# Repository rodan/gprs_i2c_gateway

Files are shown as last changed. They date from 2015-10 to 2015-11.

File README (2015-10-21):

  this is a re-run of a previous project [1], 
  but instead of the Atmel AVR 328p a Texas Instruments MSP430F5510 is used

  it is still under development, but the firmware will be able to

   - talk to a number of i2c sensors
   - buffer data into a fram memory chip
   - send data via gprs to an online server
   - use a minimal amount of energy

  there are 3 components in this repository:
  firmware  - contains the C code for the microcontroller
  hardware  - open source hardware for the main board
  server    - server-side implementation of the comm protocol

  * library dependencies for the included avr software:
  none - all is included in the repo

  * compiler toolchain used (gentoo):
        msp430-gcc-4.6.3_p20120406
        msp430mcu-20120716
        msp430-binutils-2.22_p20120911
        msp430-libc-20120716
        mspdebug-0.21

  * development is done using
        MSP430-5510STK [2]

  * dependencies for the server-side software:

  sqlite      http://www.sqlite.org/
  gnuplot     http://www.gnuplot.info/

  * sensors used:

  SHT15 Humidity and Temperature Sensor
  Honeywell HSCMRNN030PA2A3 pressure sensor - mouser part: 785-HSCMRNN030PA2A3

  Author:          Petre Rodan <petre.rodan@simplex.ro>
  Available from:  https://github.com/rodan/gprs_i2c_gateway
  License:         GNU GPLv3

[1]  https://github.com/rodan/solar-sensor
[2]  https://www.olimex.com/Products/MSP430/Starter/MSP430-5510STK/

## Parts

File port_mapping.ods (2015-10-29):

Project: | gprs i2c gateway
port | designation | use | PxDIR - in=0, out=1 | PxSEL - special fct disabled=0 enabled=1 | PxOUT - low=0, high=1 | PxREN - pullup(down)disabled=0 enabled=1
P1.0 | TA0CLK/ACLK |  | 0 | 0 | 0 | 0
P1.1 | TA0.0 | CE | 1 | 0 | 0 | 0
P1.2 | TA0.1 | CHG | 0 | 0 | 0 | 0
P1.3 | TA0.2 | RTS _O | 1 | 0 | 0 | 0
P1.4 | TA0.3 | CTS _I | 0 | 0 | 0 | 1
P1.5 | TA0.4 | RI _I | 0 | 0 | 0 | 0
P1.6 | TA1CLK | DTR _O | 1 | 0 | 0 | 0
P1.7 | TA1.0 |  | 0 | 0 | 0 | 0
 |  |  | 4A | 00 | 00 | 10
P2.0 | TD0 |  | 0 | 0 | 0 | 0
 |  |  | 00 | 00 | 00 | 00
P4.0 | PM_UCB1STE/PM_UCA1CLK | GPRS_PWRKEY _O | 1 | 0 | 0 | 0
P4.1 | PM_UCB1SIMO/PM_UCB1SDA | GPRS_VBAT _O | 1 | 0 | 0 | 0
P4.2 | PM_UCB1SOMI/PM_UCB1SCL | uart rx | 0 | 0 | 0 | 0
P4.3 | PM_UCB1CLK/PM_UCA1STE | uart tx | 0 | 0 | 0 | 0
P4.4 | PM_UCA1TXD/PM_UCA1SIMO | gprs rx | 0 | 0 | 0 | 0
P4.5 | PM_UCA1RXD/PM_UCA1SOMI | gprs tx | 0 | 0 | 0 | 0
P4.6 | PM_NONE | SCL | 1 | 0 | 0 | 0
P4.7 | PM_NONE | SDA | 1 | 0 | 0 | 0
 |  |  | C3 | 00 | 00 | 00
P5.0 | A8/VeREF+ |  | 0 | 0 | 0 | 0
P5.1 | A9/VeREF- |  | 0 | 0 | 0 | 0
P5.2 | XT2IN |  | 0 | 0 | 0 | 0
P5.3 | XT2OUT |  | 0 | 0 | 0 | 0
P5.4 | XIN | LF crystal | 0 | 1 | 0 | 0
P5.5 | XOUT | LF crystal | 0 | 1 | 0 | 0
 |  |  | 00 | 30 | 00 | 00
P6.0 | A0 | I2C_EN _O | 1 | 0 | 0 | 0
P6.1 | A1 | status LED _O | 1 | 0 | 0 | 0
P6.2 | A2 | RAW_DIV | 0 | 0 | 0 | 0
P6.3 | A3 | BAT_DIV | 0 | 0 | 0 | 0
 |  |  | 03 | 00 | 00 | 00

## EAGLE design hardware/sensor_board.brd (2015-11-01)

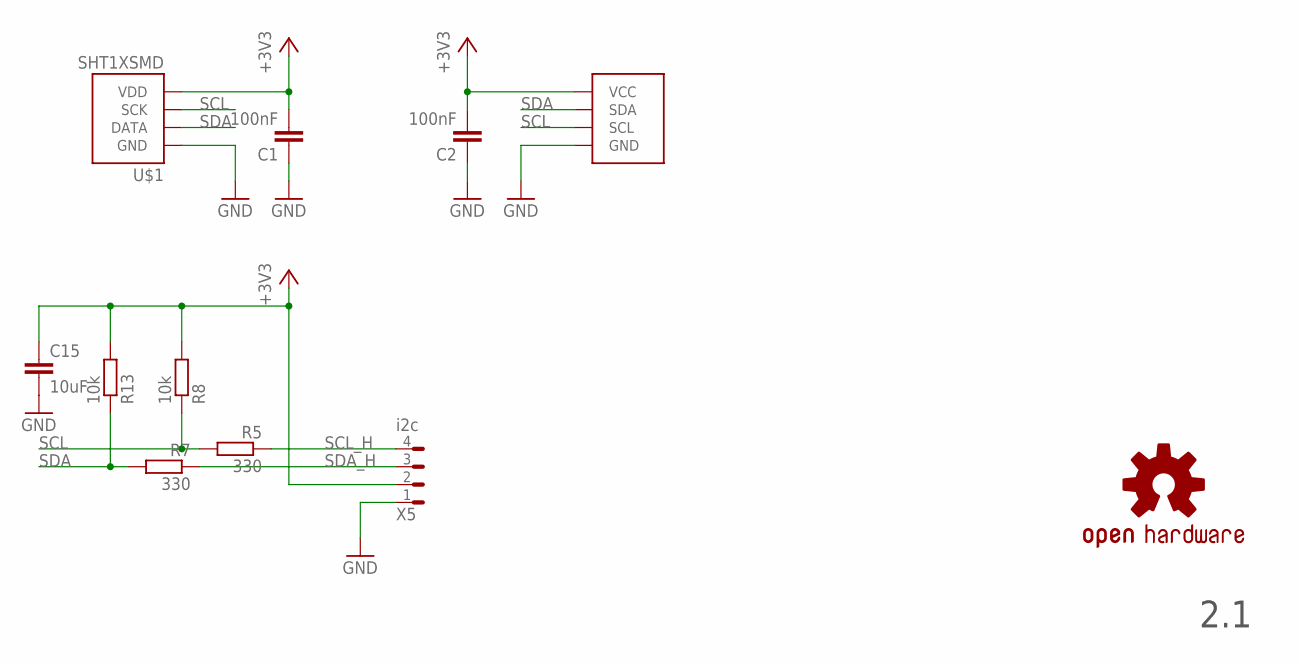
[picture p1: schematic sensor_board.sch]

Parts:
C1, C2: 100nF; C0805
C15: 10uF; C1206
R5, R7: 330; R0805W
R8, R13: 10k; R0805W
U$1: SHT1XSMD; SHT1X
U$2: HONEYWELL_HSC; HONEYWELL_8_SMT
U$7: OSHW-LOGOM; OSHW-LOGO-M
X5: i2c; 0530480401

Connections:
+3V3: C1.2, C2.2, C15.1, R8.2, R13.2, U$1.4 (VDD), U$2.P$2 (VCC), X5.2 (3)
GND: C1.1, C2.1, C15.2, U$1.1 (GND), U$2.P$1 (GND), X5.1 (4)
SCL: R5.2, R8.1, U$1.3 (SCK), U$2.P$4 (SCL)
SCL_H: R5.1, X5.4 (1)
SDA: R7.2, R13.1, U$1.2 (DATA), U$2.P$3 (SDA)
SDA_H: R7.1, X5.3 (2)

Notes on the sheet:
2.1

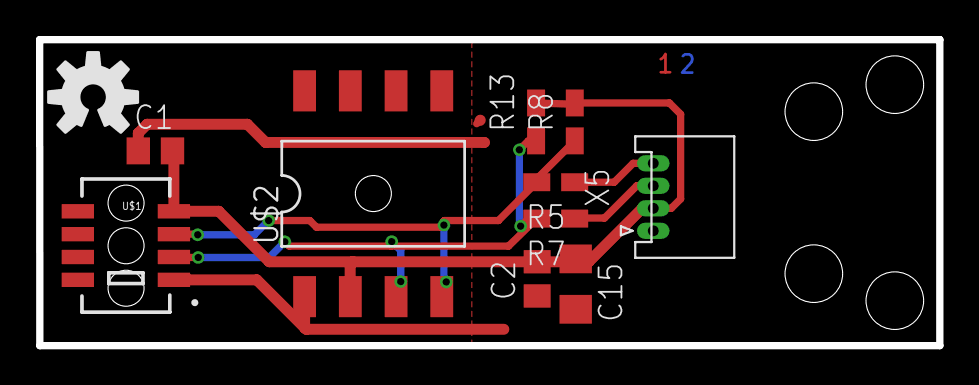
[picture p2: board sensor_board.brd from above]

Board: 2 copper layers, 50.0 x 17.0 mm, 11 parts (0 on the bottom side), 6 nets.

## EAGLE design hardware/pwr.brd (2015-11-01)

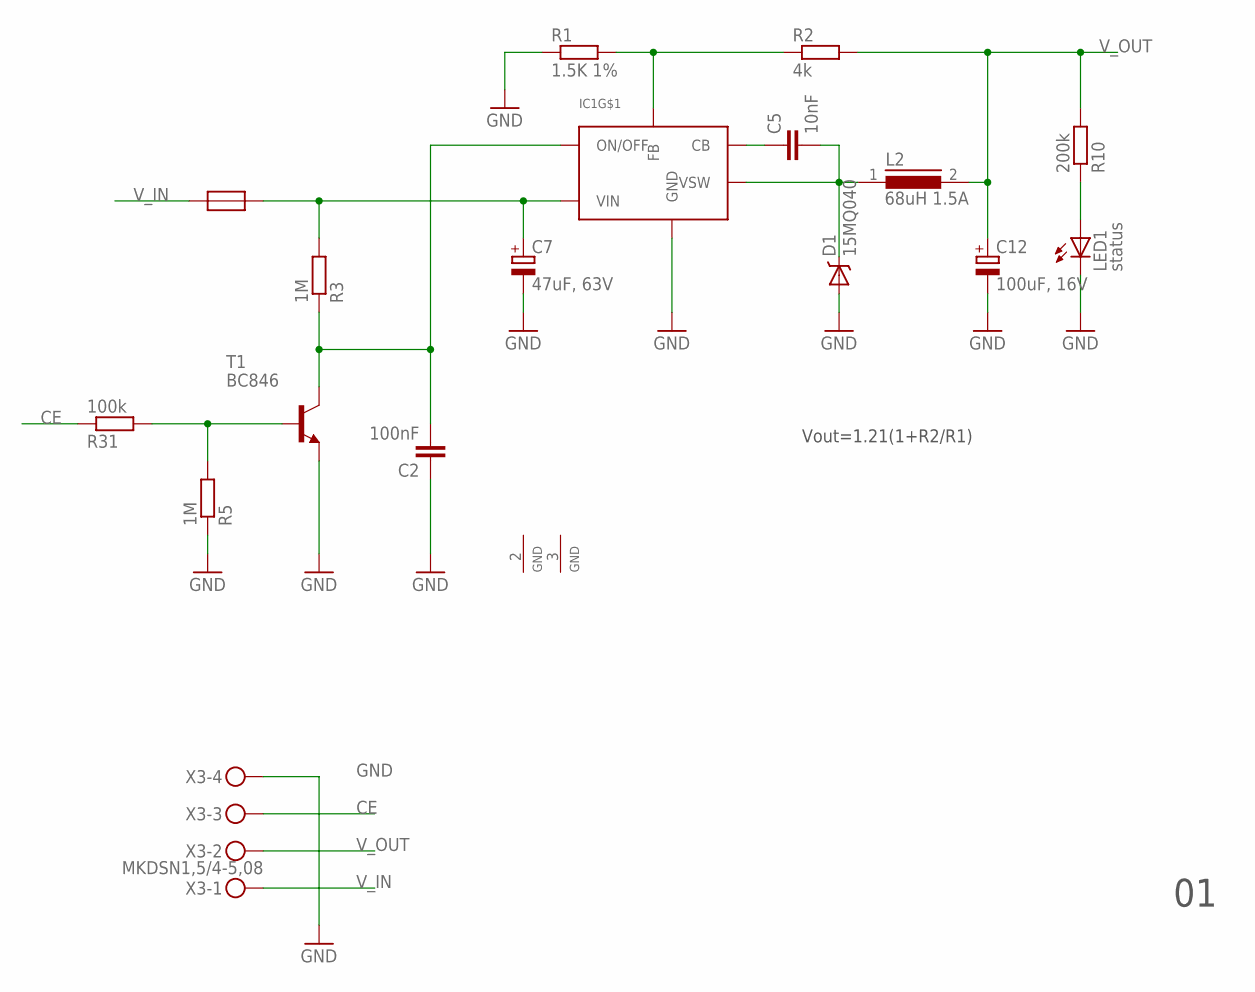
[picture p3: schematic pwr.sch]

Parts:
C2: 100nF; C0805
C5: 10nF; C0805
C7: 47uF, 63V; PANASONIC_F
C12: 100uF, 16V; PANASONIC_D
D1: 15MQ040; SMA-DIODE
IC1: LM2674; SO-08
L2: 68uH 1.5A; DR125
LED1: status; CHIP-LED0805
R1: 1.5K 1%; R0805W
R2: 4k; R0805W
R3, R5: 1M; R0805W
R10: 200k; R0805W
R31: 100k; R0805W
T1: BC846; SOT23
U$1: RESETTABLE_0805; 0805W
X3: MKDSN1,5/4-5,08

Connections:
CE: R31.1, X3.3
GND: C2.1, C7.-, C12.-, D1.A, IC1.2 (GND), IC1.3 (GND), IC1.6 (GND), LED1.C, R1.1, R5.1, T1.2 (E), X3.4
unnamed: LED1.A, R10.1
unnamed: C2.2, IC1.5 (ON/OFF), R3.1, T1.3 (C)
unnamed: R5.2, R31.2, T1.1 (B)
unnamed: IC1.4 (FB), R1.2, R2.1
unnamed: C5.2, D1.C, IC1.8 (VSW), L2.1
unnamed: C5.1, IC1.1 (CB)
unnamed: C7.+, IC1.7 (VIN), R3.2, U$1.2
V_IN: U$1.1, X3.1
V_OUT: C12.+, L2.2, R2.2, R10.2, X3.2

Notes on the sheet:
Vout=1.21(1+R2/R1)

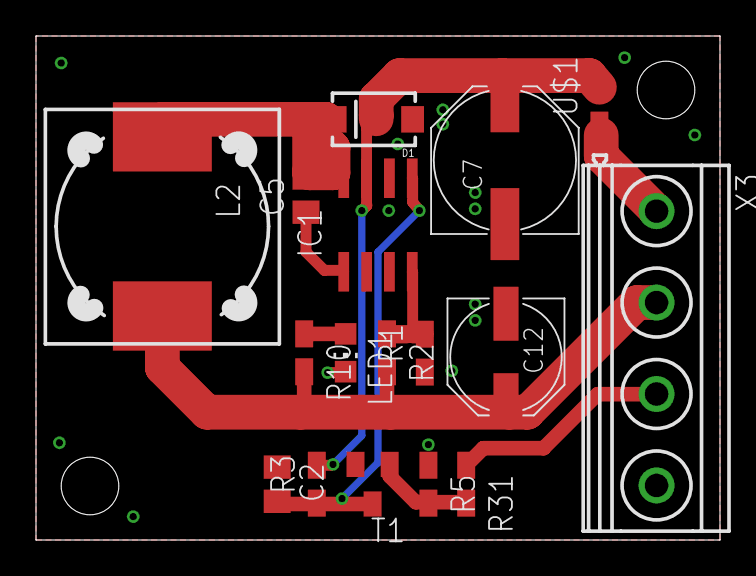
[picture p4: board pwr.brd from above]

Board: 2 copper layers, 38.0 x 28.0 mm, 17 parts (0 on the bottom side), 11 nets.

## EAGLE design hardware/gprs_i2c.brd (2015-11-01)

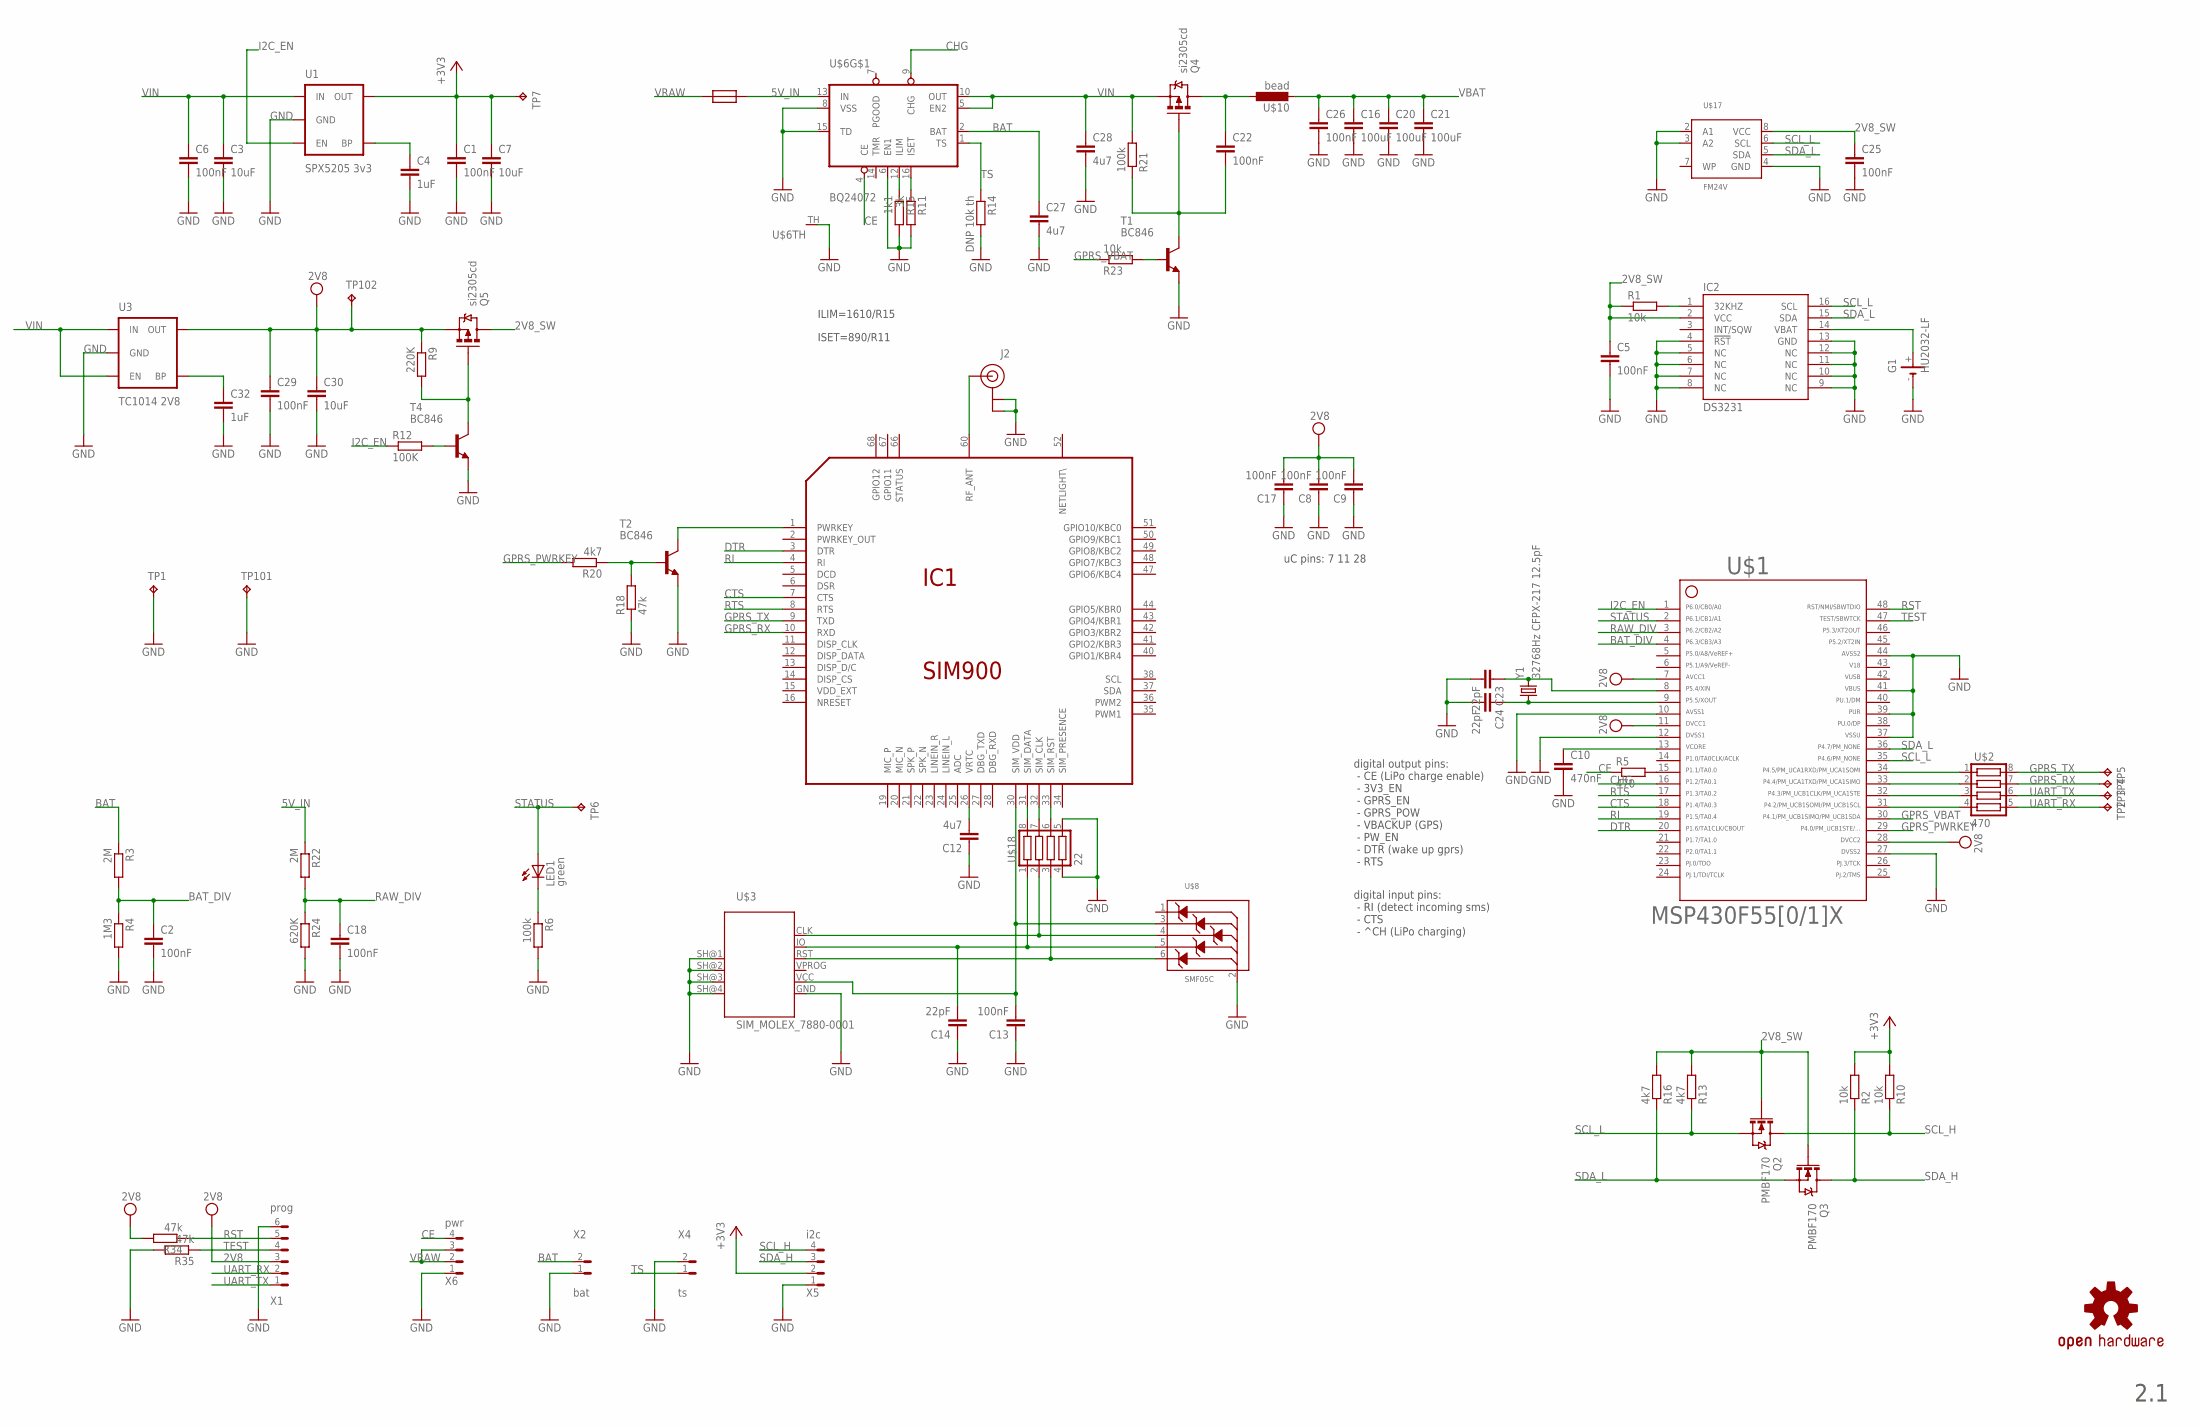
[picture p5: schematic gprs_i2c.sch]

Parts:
C1, C2, C5, C6, C8, C9, C13, C17, C18, C22, C25, C26, C29: 100nF; C0805
C3: 10uF; C0805
C4, C32: 1uF; C0805
C7, C30: 10uF; C1206
C10: 470nF; C0805
C12: 4u7; C0805
C14, C23, C24: 22pF; C0805
C16, C20, C21: 100uF; C1206
C27, C28: 4u7; C1206
G1: HU2032-LF
IC1: SIM900
IC2: DS3231; SO-16
J2: U.FL
LED1: green; CHIPLED_0805
Q2, Q3: PMBF170; SOT23-3
Q4, Q5: si2305cd; SOT23-3_POWER@1
R1, R2, R10, R23: 10k; R0805W
R3, R22: 2M; R0805W
R4: 1M3; R0805W
R5: 470; R0805W
R6, R21: 100k; R0805W
R9: 220K; R0805W
R11: 3k; R0805W
R12: 100K; R0805W
R13, R16, R20: 4k7; R0805W
R14: DNP 10k th; R0805W
R15: 1k1; R0805W
R18, R34, R35: 47k; R0805W
R24: 620K; R0805W
T1, T2, T4: BC846; SOT23
TP1, TP2, TP3, TP4, TP5, TP6, TP7, TP101, TP102: TPTP12R; TP12R
U1: SPX5205 3v3; SOT23-5
U3: TC1014 2V8; SOT23-5
U$1: MSP430F5510; PT48
U$2: 470; YC164
U$3: SIM_MOLEX_7880-0001; MOLEX_7880-0001
U$5: RESETTABLE_0805; 0805W
U$6: BQ24072; S-PVQFN-N16
U$7: OSHW-LOGOM; OSHW-LOGO-M
U$8: SMF05C; SC-88
U$10: bead; L0805W
U$17: FM24V; SO-08
U$18: 22; YC164
X1: prog; 0530470610
X2: bat; 0530480210
X4: ts; 0530480210
X5: i2c; 0530480401
X6: pwr; 0530480401
Y1: 32768Hz CFPX-217 12.5pF; CRYSTAL-SMD-3.2X1.5

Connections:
2V8: C8.2, C9.2, C17.2, C29.1, C30.1, Q5.2 (S), R9.1, R34.2, TP102.TP, U3.5 (OUT), U$1.7, U$1.11, U$1.28, X1.3
2V8_SW: C5.1, C25.1, IC2.2 (VCC), Q2.1 (G), Q3.1 (G), Q5.3 (D), R1.1, R13.2, R16.2, U$17.8 (VCC)
5V_IN: R22.1, U$5.2, U$6.13 (IN)
42: U$1.42
43: U$1.43
46: U$1.46
+3V3: C1.1, C7.1, R2.2, R10.2, TP7.TP, U1.5 (OUT), X5.2 (3)
BAT: C27.1, R3.1, U$6.2 (BAT), X2.2 (1)
BAT_DIV: C2.1, R3.2, R4.1, U$1.4
CE: R5.1, U$6.4 (CE), X6.4 (1)
CHG: U$1.16, U$6.9 (CHG)
CTS: IC1.7 (CTS), U$1.18
DTR: IC1.3 (DTR), U$1.20
GND: C1.2, C2.2, C3.2, C4.2, C5.2, C6.2, C7.2, C8.1, C9.1, C10.2, C12.1, C13.1, C14.1, C16.2, C17.1, C18.2, C20.2, C21.2, C23.2, C24.2, C25.2, C26.2, C27.2, C28.2, C29.2, C30.2, C32.2, G1.-, IC1.17 (GND), IC1.18 (GND), IC1.29 (GND), IC1.39 (GND), IC1.45 (GND), IC1.46 (GND), IC1.53 (GND), IC1.54 (GND), IC1.58 (GND), IC1.59 (GND), IC1.61 (GND), IC1.62 (GND), IC1.63 (GND), IC1.64 (GND), IC1.65 (GND), IC2.4 (!RST), IC2.5 (NC), IC2.6 (NC), IC2.7 (NC), IC2.8 (NC), IC2.9 (NC), IC2.10 (NC), IC2.11 (NC), IC2.12 (NC), IC2.13 (GND), J2.P$1 (GND), J2.P$2 (GND), R4.2, R6.2, R11.2, R14.2, R15.2, R18.1, R24.2, R35.2, T1.2 (E), T2.2 (E), T4.2 (E), TP1.TP, TP101.TP, U1.2 (GND), U3.2 (GND), U$1.10, U$1.12, U$1.27, U$1.37, U$1.39, U$1.41, U$1.44, U$3.GND, U$3.SH@1 (SH), U$3.SH@2 (SH), U$3.SH@3 (SH), U$3.SH@4 (SH), U$6.6 (EN1), U$6.8 (VSS), U$6.15 (TD), U$6.TH, U$8.2 (ANODE), U$17.2 (A1), U$17.3 (A2), U$17.4 (GND), U$18.4, U$18.5, X1.6, X2.1 (2), X4.2 (1), X5.1 (4), X6.1 (4)
GPRS_PWRKEY: R20.2, U$1.29
GPRS_RX: IC1.10 (RXD), TP4.TP, U$2.7
GPRS_TX: IC1.9 (TXD), TP5.TP, U$2.8
GPRS_VBAT: R23.1, U$1.30
I2C_EN: R12.1, U1.3 (EN), U$1.1
unnamed: U$1.32, U$2.3
unnamed: C4.1, U1.4 (BP)
unnamed: U$1.31, U$2.4
unnamed: U$1.33, U$2.2
unnamed: G1.+, IC2.14 (VBAT)
unnamed: C10.1, U$1.13
unnamed: R23.2, T1.1 (B)
unnamed: LED1.C, R6.1
unnamed: IC2.1 (32KHZ), R1.2
unnamed: U$1.34, U$2.1
unnamed: R5.2, U$1.15
unnamed: Q5.1 (G), R9.2, T4.3 (C)
unnamed: R12.2, T4.1 (B)
unnamed: IC1.31 (SIM_DATA), U$18.8
unnamed: IC1.32 (SIM_CLK), U$18.7
unnamed: IC1.33 (SIM_RST), U$18.6
unnamed: C24.1, U$1.9, Y1.P$1 (1)
unnamed: C23.1, U$1.8, Y1.P$2 (2)
unnamed: R11.1, U$6.16 (ISET)
unnamed: R15.1, U$6.12 (ILIM)
unnamed: R18.2, R20.1, T2.1 (B)
unnamed: IC1.60 (RF_ANT), J2.P$3 (SIGNAL)
unnamed: C22.2, Q4.1 (G), R21.1, T1.3 (C)
unnamed: C22.1, Q4.3 (D), U$10.1
unnamed: C32.1, U3.4 (BP)
PWRKEY: IC1.1 (PWRKEY), T2.3 (C)
RAW_DIV: C18.1, R22.2, R24.1, U$1.3
RI: IC1.4 (RI), U$1.19
RST: R34.1, U$1.48, X1.5
RTS: IC1.8 (RTS), U$1.17
SCL_H: Q2.3 (D), R10.1, X5.4 (1)
SCL_L: IC2.16 (SCL), Q2.2 (S), R13.1, U$1.35, U$17.6 (SCL)
SDA_H: Q3.3 (D), R2.1, X5.3 (2)
SDA_L: IC2.15 (SDA), Q3.2 (S), R16.1, U$1.36, U$17.5 (SDA)
SIMLOCK_CLK: U$3.CLK, U$8.4 (CATODE3), U$18.2
SIMLOCK_IO: C14.2, U$3.IO, U$8.5 (CATODE4), U$18.1
SIMLOCK_RST: U$3.RST, U$8.6 (CATODE5), U$18.3
SIM_VCC: C13.2, IC1.30 (SIM_VDD), U$3.VCC, U$8.3 (CATODE2)
STATUS: LED1.A, TP6.TP, U$1.2
TEST: R35.1, U$1.47, X1.4
TS: R14.1, U$6.1 (TS), X4.1 (2)
UART_RX: TP2.TP, U$2.5, X1.2
UART_TX: TP3.TP, U$2.6, X1.1
VBAT: C16.1, C20.1, C21.1, C26.1, IC1.55 (VBAT), IC1.56 (VBAT), IC1.57 (VBAT), U$10.2
VIN: C3.1, C6.1, C28.1, Q4.2 (S), R21.2, U1.1 (IN), U3.1 (IN), U3.3 (EN), U$6.5 (EN2), U$6.10 (OUT)
VRAW: U$5.1, X6.2 (3), X6.3 (2)
VRTC: C12.2, IC1.26 (VRTC)

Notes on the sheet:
2.1
uC pins: 7 11 28
digital output pins: - CE (LiPo charge enable) - 3V3_EN - GPRS_EN - GPRS_POW - VBACKUP (GPS) - PW_EN - DTR (wake up gprs) - RTS
digital input pins: - RI (detect incoming sms) - CTS - ^CH (LiPo charging)
ILIM=1610/R15
ISET=890/R11

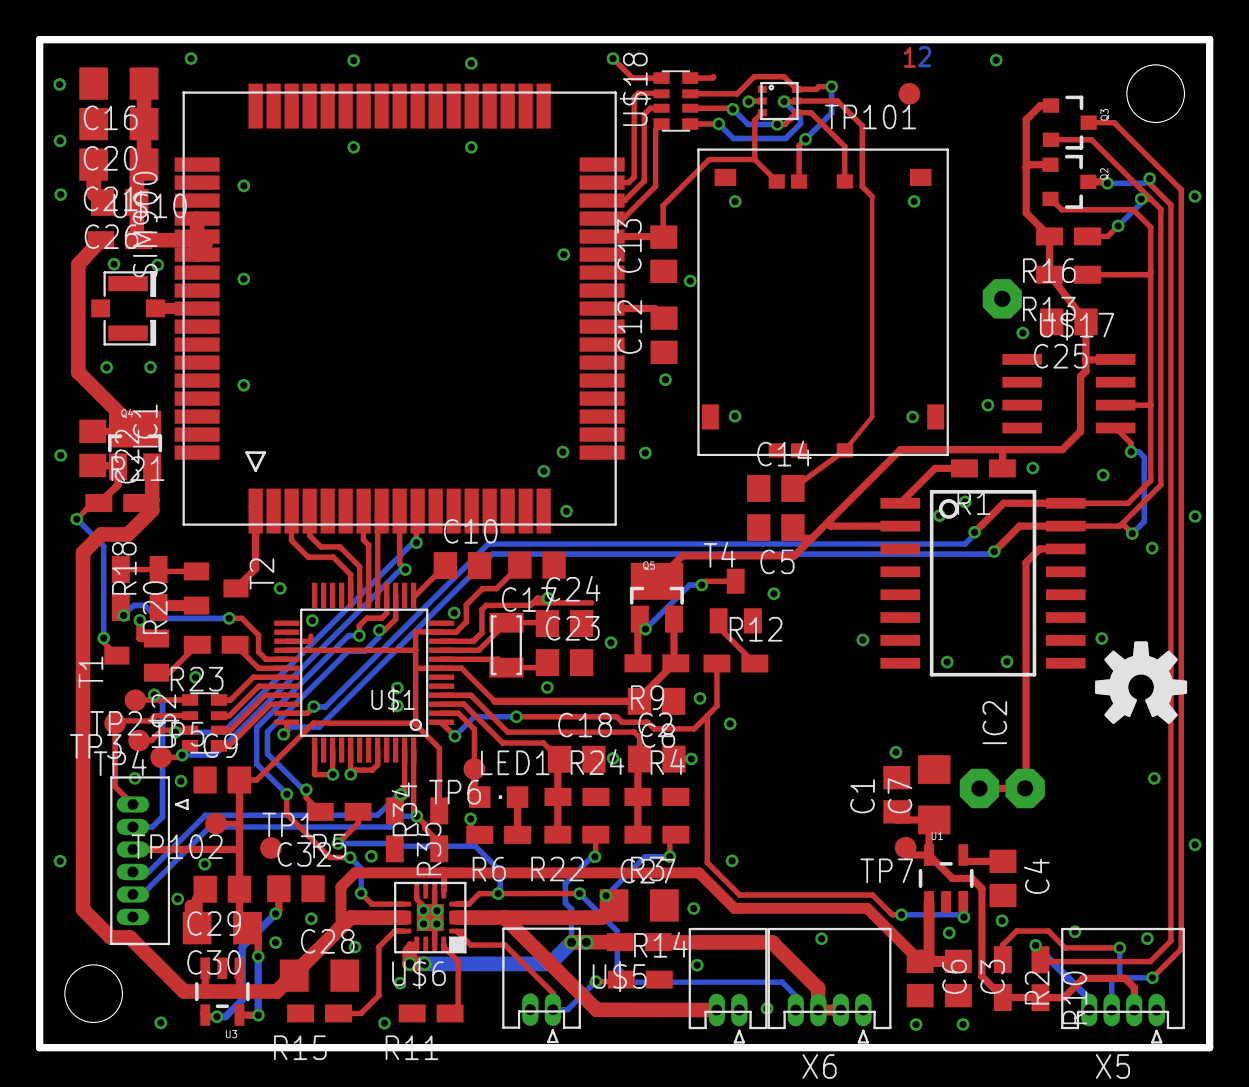
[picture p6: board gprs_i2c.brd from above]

Board: 4 copper layers, 65.0 x 56.0 mm, 89 parts (1 on the bottom side), 63 nets.

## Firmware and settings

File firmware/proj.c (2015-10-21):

//  weather station system based on a MSP430F5510 uC
//
//  author:          Petre Rodan <petre.rodan@simplex.ro>
//  available from:  https://github.com/rodan/
//  license:         GNU GPLv3

#include <stdio.h>
#include <string.h>

#include "proj.h"
#include "drivers/sys_messagebus.h"
#include "drivers/rtc.h"
#include "drivers/timer_a0.h"
#include "drivers/uart0.h"
#include "drivers/uart1.h"
#include "drivers/adc.h"
#include "drivers/sim900.h"
#include "drivers/flash.h"
#include "drivers/fm24.h"
#include "drivers/fm24_memtest.h"
#include "qa.h"

uint32_t rtca_set_next = 0;

uint32_t status_show_next = 0;

uint32_t adc_check_next = 0;
uint16_t adc_check_interval = 15;

uint32_t movement_next = 0;

static void parse_gprs(enum sys_message msg)
{
    uart0_tx_str((char *)uart1_rx_buf, uart1_p);
    sim900_parse_rx((char *)uart1_rx_buf, uart1_p);
}

static void parse_UI(enum sys_message msg)
{
    parse_user_input();

    uart0_p = 0;
    uart0_rx_enable = 1;
    LED_OFF;
}

static void schedule(enum sys_message msg)
{

    // battery related
    if (rtca_time.sys > adc_check_next) {
        adc_read();

        adc_check_next = rtca_time.sys + adc_check_interval;

        if ((stat.v_raw > 400) && (stat.v_raw < 550)) {
            if (CHARGING_STOPPED) {
                if (stat.should_charge) {
                    CHARGE_DISABLE;
                    stat.should_charge = false;
                    adc_check_next = rtca_time.sys + 300;
                } else {
                    if (stat.v_bat < 390) {
                        CHARGE_ENABLE;
                        stat.should_charge = true;
                        charge_start = rtca_time.sys;
                    }
                }
            } else {
                if (rtca_time.sys > charge_start + 36000) {
                    CHARGE_DISABLE;
                    stat.should_charge = false;
                    adc_check_next = rtca_time.sys + 3600;
                }
            }
        } else {
            CHARGE_DISABLE;
            stat.should_charge = false;
        }
    }

    if (rtca_time.sys > gps_trigger_next) {
        // state machine
    }

    // GPRS related
    // force the HTTP POST from time to time
    if (rtca_time.sys > gprs_tx_next) {
        if (gprs_tx_trig & TG_NOW_MOVING) {
            gprs_tx_next = rtca_time.sys + s.gprs_moving_tx_interval;
        } else {
            gprs_tx_next = rtca_time.sys + s.gprs_static_tx_interval;
        }
        sim900.flags |= TX_FIX_RDY;
    }

    if (sim900.flags & BLACKOUT) {
       if (rtca_time.sys > gprs_blackout_lift) {
           sim900.flags &= ~BLACKOUT;
       }
    }

    if (((rtca_time.sys > gprs_trigger_next) || (sim900.flags & TX_FIX_RDY)) && 
            !(sim900.flags & TASK_IN_PROGRESS)) {

        // time to act
        adc_read();
        gprs_trigger_next = rtca_time.sys + s.gprs_loop_interval;

        if (stat.v_bat > 350) {
            // if battery voltage is below ~3.4v
            // the sim will most likely lock up while trying to TX
            if (!(sim900.flags & BLACKOUT)) {
                sim900_exec_default_task();
            }
        }
    }
}

int main(void)
{
    main_init();
    rtca_init();
    timer_a0_init();
    uart0_init();
    sim900_init_messagebus();
    sim900.next_state = SIM900_OFF;

    settings_init(SEGMENT_B, VERSION_BASED);
    //settings_apply();

    m.e = 0x0;
    m.seg[0] = 0x0;
    m.seg_num = 1;

    stat.http_post_version = POST_VERSION;
    stat.fix_id = 1;

    sim900.imei[0] = 0;
    sim900.flags = 0;


    gps_trigger_next = 0;
    gprs_trigger_next = s.gprs_loop_interval;

    rtca_set_next = 0;
    rtc_not_set = 1;
    gps_next_state = MAIN_GPS_IDLE;

    if (s.gps_invalidate_interval > s.gps_loop_interval) {
        s.gps_invalidate_interval = s.gps_loop_interval;
    }
   
    gprs_tx_trig = 0;
    gprs_tx_next = s.gprs_static_tx_interval;

    gprs_blackout_lift = 0;

    uart0_tx_str("solar sensor\r\n", 14);
    display_menu();

    sys_messagebus_register(&schedule, SYS_MSG_RTC_SECOND);
    sys_messagebus_register(&parse_UI, SYS_MSG_UART0_RX);
    sys_messagebus_register(&parse_gprs, SYS_MSG_UART1_RX);

#ifdef FM24_HAS_SLEEP_MODE
    //fm24_sleep();
#endif

    // main loop
    while (1) {
        _BIS_SR(LPM3_bits + GIE);
        //wake_up();
#ifdef USE_WATCHDOG
        // reset watchdog counter
        WDTCTL = (WDTCTL & 0xff) | WDTPW | WDTCNTCL;
#endif
        // new messages can be sent from within a check_events() call, so 
        // parse the message linked list multiple times
        check_events();
        check_events();
        check_events();

#ifdef FM24_HAS_SLEEP_MODE
        // sleep
        //if (fm24_status & FM24_AWAKE) {
        //    fm24_sleep();
        //}
#endif

        // P4.0 and P4.1
        //P4SEL &= ~0x3;
        
        /*
        PMMCTL0_H = 0xA5;
        SVSMHCTL &= ~SVMHE;
        SVSMLCTL &= ~(SVSLE+SVMLE);
        PMMCTL0_H = 0x00;
        */
    }
}

void main_init(void)
{

    // watchdog triggers after 4 minutes when not cleared
#ifdef USE_WATCHDOG
    WDTCTL = WDTPW + WDTIS__8192K + WDTSSEL__ACLK + WDTCNTCL;
#else
    WDTCTL = WDTPW + WDTHOLD;
#endif
    //SetVCore(3);

    // enable LF crystal
    P5SEL |= BIT5 + BIT4;
    UCSCTL6 &= ~(XT1OFF | XT1DRIVE0);

    P1SEL = 0x0;
    P1DIR = 0x0;
    //P1REN = 0x2;
    // make sure CTS is pulled low so the software doesn't get stuck 
    // in case the sim900 is missing - or broken.
    P1REN = 0x0;
    P1OUT = 0x0;

    P2SEL = 0x0;
    P2DIR = 0x0;
    P2OUT = 0x0;

    P3SEL = 0x0;
    P3DIR = 0x1f;
    P3OUT = 0x0;

    P4DIR = 0x0;
    P4OUT = 0x0;

    // mappings
    PMAPPWD = 0x02D52;
    // uart interface
    P4MAP2 = PM_UCA0TXD;
    P4MAP3 = PM_UCA0RXD;
    P4SEL |= 0xc;
    // try to also send uart0 tx to 4.1 XXX
    //P4MAP1 = PM_UCA0TXD;
    //P4SEL |= 0x2;
    PMAPPWD = 0;

    //P5SEL is set above
    P5DIR = 0xf;
    P5OUT = 0x0;

    P6SEL = 0x0;
    P6DIR = 0x0;
    P6OUT = 0x0;

    PJDIR = 0xFF;
    PJOUT = 0x00;

    // disable VUSB LDO and SLDO
    USBKEYPID = 0x9628;
    USBPWRCTL &= ~(SLDOEN + VUSBEN);
    USBKEYPID = 0x9600;

}

void check_events(void)
{
    struct sys_messagebus *p = messagebus;
    enum sys_message msg = 0;

    // drivers/timer0a
    if (timer_a0_last_event) {
        msg |= timer_a0_last_event;
        timer_a0_last_event = 0;
    }
    // drivers/uart0
    if (uart0_last_event & UART0_EV_RX) {
        msg |= BITA;
        uart0_last_event = 0;
    }
    // drivers/uart1
    if (uart1_last_event & UART1_EV_RX) {
        msg |= BITB;
        uart1_last_event = 0;
    }
    // drivers/rtca
    if (rtca_last_event & RTCA_EV_SECOND) {
        msg |= BITF;
        rtca_last_event = 0;
    }
    while (p) {
        // notify listener if he registered for any of these messages
        if (msg & p->listens) {
            p->fn(msg);
        }
        p = p->next;
    }
}

void settings_init(uint8_t * addr, const uint8_t location)
{
    uint8_t *src_p, *dst_p;
    uint8_t i;

    src_p = addr;
    dst_p = (uint8_t *) & s;
    if (((*src_p) != FLASH_VER) || (location)) {
        src_p = (uint8_t *) & defaults;
    }
    for (i = 0; i < sizeof(s); i++) {
        *dst_p++ = *src_p++;
    }
}

void settings_apply()
{
}

void adc_read()
{
    uint16_t q_bat = 0, q_raw = 0;
    uint32_t v_bat, v_raw;

    adc10_read(3, &q_bat, REFVSEL_1);
    adc10_read(2, &q_raw, REFVSEL_1);
    v_bat = (uint32_t) q_bat *s.vref * DIV_BAT / 10000;
    v_raw = (uint32_t) q_raw *s.vref * DIV_RAW / 10000;
    stat.v_bat = v_bat;
    stat.v_raw = v_raw;
    adc10_halt();
}

void store_pkt()
{
}

void gps_enable(void)
{
    P6OUT |= BIT0;
    P4SEL |= 0xc;
}

void gps_disable(void)
{
    P6OUT &= ~BIT0;
    P4SEL &= ~0xc;
}

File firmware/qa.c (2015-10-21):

#include <stdio.h>
#include <string.h>

#include "drivers/uart0.h"
#include "drivers/sim900.h"
#include "drivers/uart1.h"
#include "drivers/timer_a0.h"
#include "drivers/flash.h"
#include "drivers/rtc.h"
#include "version.h"
#include "sensirion.h"
#include "serial_bitbang.h"
#include "hsc_ssc_i2c.h"
#include "ds3231.h"
#include "qa.h"

void display_memtest(const uint32_t start_addr, const uint32_t stop_addr, fm24_test_t test)
{
    uint32_t el;
    uint32_t rows_tested;

    snprintf(str_temp, STR_LEN, " \e[36;1m*\e[0m testing %lx - %lx with pattern #%d\t", start_addr, stop_addr, test);
    uart0_tx_str(str_temp, strlen(str_temp));

    el = fm24_memtest(start_addr, stop_addr, test, &rows_tested);

    if (el == 0) { 
        snprintf(str_temp, STR_LEN, "%lu bytes tested \e[32;1mok\e[0m\r\n", rows_tested * 8);
    } else {
        snprintf(str_temp, STR_LEN, "%lu bytes tested with \e[31;1m%lu errors\e[0m\r\n", rows_tested * 8, el );
    }
    uart0_tx_str(str_temp, strlen(str_temp));
}

void display_menu(void)
{
    snprintf(str_temp, STR_LEN,
            "\r\n --- ss build #%d\r\n  available commands:\r\n", BUILD);
    uart0_tx_str(str_temp, strlen(str_temp));

    snprintf(str_temp, STR_LEN, " \e[33;1m?\e[0m              - show menu\r\n" );
    uart0_tx_str(str_temp, strlen(str_temp));

    snprintf(str_temp, STR_LEN, " \e[33;1m!gprs [on/off]\e[0m - gprs power on/off\r\n" );
    uart0_tx_str(str_temp, strlen(str_temp));

    snprintf(str_temp, STR_LEN, " \e[33;1m!gprs init\e[0m     - gprs initial setup\r\n" );
    uart0_tx_str(str_temp, strlen(str_temp));

    snprintf(str_temp, STR_LEN, " \e[33;1m!gprs def\e[0m      - gprs start default task\r\n" );
    uart0_tx_str(str_temp, strlen(str_temp));

    snprintf(str_temp, STR_LEN, " \e[33;1m!sht\e[0m           - get SHT measurment\r\n" );
    uart0_tx_str(str_temp, strlen(str_temp));

    snprintf(str_temp, STR_LEN, " \e[33;1m!hsc\e[0m           - get HSC measurment\r\n" );
    uart0_tx_str(str_temp, strlen(str_temp));

    snprintf(str_temp, STR_LEN, " \e[33;1m!rtc\e[0m           - get RTC readout\r\n" );
    uart0_tx_str(str_temp, strlen(str_temp));

    snprintf(str_temp, STR_LEN, " \e[33;1m!mem store\e[0m     - store packet\r\n" );
    uart0_tx_str(str_temp, strlen(str_temp));

    snprintf(str_temp, STR_LEN, " \e[33;1m!mem test\e[0m      - memtest\r\n" );
    uart0_tx_str(str_temp, strlen(str_temp));

    snprintf(str_temp, STR_LEN, " \e[33;1m!mem read\e[0m      - read all external mem\r\n" );
    uart0_tx_str(str_temp, strlen(str_temp));

    snprintf(str_temp, STR_LEN, " \e[33;1m!flash read\e[0m    - read flash segment B\r\n" );
    uart0_tx_str(str_temp, strlen(str_temp));

    snprintf(str_temp, STR_LEN, " \e[33;1m!flash clear\e[0m   - clear flash segment B\r\n" );
    uart0_tx_str(str_temp, strlen(str_temp));

    snprintf(str_temp, STR_LEN, " \e[33;1m!chg [on/off]\e[0m  - charge on/off\r\n" );
    uart0_tx_str(str_temp, strlen(str_temp));

    snprintf(str_temp, STR_LEN, " \e[33;1m!stat\e[0m          - system status\r\n" );
    uart0_tx_str(str_temp, strlen(str_temp));

}

void parse_user_input(void)
{
    char f = uart0_rx_buf[0];
    char *in = (char *) uart0_rx_buf;
    uint8_t *src_p;
    uint16_t i;
    uint8_t j;
    uint8_t row[8];
    uint8_t zeroes[128];
    struct ts t;

    if (f == '?') {
        display_menu();
    } else if (f == '!') {
        if (strstr(in, "gprs")) {
            if (strstr(in, "def")) {
            // gprs default task
                sim900_exec_default_task();
            } else if (strstr(in, "on")) {
            // gprs on
                sim900_start();
            } else if (strstr(in, "off")) {
            // gprs off
                sim900_halt();
            } else if (strstr(in, "init")) {
            // gprs init
                uart1_init(2400);
                sim900.cmd = CMD_FIRST_PWRON;
                sim900.next_state = SIM900_IDLE;
                timer_a0_delay_noblk_ccr2(SM_STEP_DELAY);
            }
        } else if (strstr(in, "rtcset")) {
            t.sec = inp2toi(in, 7);
            t.min = inp2toi(in, 9);
            t.hour = inp2toi(in, 11);
            t.wday = in[13] - 48;
            t.mday = inp2toi(in, 14);
            t.mon = inp2toi(in, 16);
            t.year = inp2toi(in, 18) * 100 + inp2toi(in, 20);
            if (DS3231_set(t) == EXIT_SUCCESS) {
                uart0_tx_str("ok\r\n", 4);
            } else {
                uart0_tx_str("fail\r\n", 6);
            }
        } else if (strstr(in, "rtc")) {

            if (DS3231_get(&t) == EXIT_FAILURE) {
                uart0_tx_str("fail\r\n", 6);
            }

#ifdef CONFIG_UNIXTIME
            snprintf(str_temp, STR_LEN, "%d.%02d.%02d %02d:%02d:%02d %ld\r\n", t.year,
                t.mon, t.mday, t.hour, t.min, t.sec, t.unixtime);
#else
            snprintf(str_temp, STR_LEN, "%d.%02d.%02d %02d:%02d:%02d\r\n", t.year,
                t.mon, t.mday, t.hour, t.min, t.sec);
#endif
            uart0_tx_str(str_temp, strlen(str_temp));
        } else if (strstr(in, "sht")) {
            uint16_t t2, rh;

            if (sht_get_meas(&t2, &rh) == EXIT_SUCCESS) {
                snprintf(str_temp, STR_LEN, "%d.%02ddC ", t2/100, t2%100);
                uart0_tx_str(str_temp, strlen(str_temp));
                snprintf(str_temp, STR_LEN, "%d.%02drH\r\n", rh/100, rh%100);
                uart0_tx_str(str_temp, strlen(str_temp));
            } else {
                uart0_tx_str("fail\r\n", 6);
            }
        } else if (strstr(in, "hsc")) {
            int16_t t;
            uint32_t p;
            struct cs_raw ps;
            uint8_t rv1;

            rv1 = ps_get_raw(PS_SLAVE_ADDR, &ps);
            if (rv1 == I2C_ACK) {
                ps_convert(ps, &p, &t, OUTPUT_MIN, OUTPUT_MAX, PRESSURE_MIN, PRESSURE_MAX);
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

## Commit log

2015-10-21 add schematic
    [gprs_i2c.brd, gprs_i2c.sch]
2015-10-22 pcb routing stage1
    [gprs_i2c.brd, gprs_i2c.sch, port_mapping.ods]
2015-10-23 pcb reouting part2
    [gprs_i2c.brd, gprs_i2c.sch]
2015-10-23 add sensor board
    [gprs_i2c.brd, sensor_board.brd, sensor_board.sch]
2015-10-28 move CE and CHG ports
    [gprs_i2c.brd, gprs_i2c.sch]
2015-10-29 update port mappings
    [port_mapping.ods]
2015-10-30 pcb verified
    [gprs_i2c.brd, gprs_i2c.sch, sensor_board.brd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]
2015-10-31 add pwr board
    [pwr.brd, pwr.sch]
2015-11-01 pwr board width decrease
    [pwr.brd, pwr.sch]
2015-11-01 pwr board width decrease
    [pwr.brd]
2015-11-01 board ready
    [gprs_i2c.brd, pwr.brd, pwr.sch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]
2015-11-01 boards verified
    [pwr.brd, sensor_board.brd]

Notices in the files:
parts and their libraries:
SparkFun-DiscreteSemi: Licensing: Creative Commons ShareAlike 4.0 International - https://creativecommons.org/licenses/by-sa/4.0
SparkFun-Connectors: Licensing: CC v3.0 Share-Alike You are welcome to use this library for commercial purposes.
